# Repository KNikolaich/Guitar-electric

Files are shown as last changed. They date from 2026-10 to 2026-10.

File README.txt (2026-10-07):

ПРЕДУСИЛИТЕЛЬ ДЛЯ ГИТАРЫ: буфер + 2-полосный темброблок, 1S Li-ion,
громкость B500K push-pull (актив/пассив), светодиод питания
=============================================================================

СОСТАВ
  kicad/            проект KiCad 7+ (схема A3, плата, файл проекта)
  schematic.pdf     принципиальная схема (детали «вне платы» — в пунктирной рамке)
  etching/          для ЛУТ / фоторезиста, масштаб 1:1
     1_ETCH_bottom_copper_print_100pct.pdf   <- ПЕЧАТАТЬ ЭТО
     2_bottom_copper_as_seen_from_copper_side.pdf  (для сверки)
     3_assembly_top_100pct.pdf               расстановка деталей
  gerbers/          Gerber + сверловка (1 слой) для заказа на фабрике
  perfboard/        макетки: 30x70 мм (24x10 отв., компактная) и 61x41 мм (24x16 отв.)
  wiring_guitar.png проводка в корпусе: звукосниматели, RV1 push-pull, джек, TP4056, LED
  BOM.csv           перечень деталей (выводная плата)
  --- SMD-вариант конечной платы 60x29 мм ---
  kicad_smd/        проект KiCad: схема (та же, футпринты SMD) + плата
  etching_smd/      1_ETCH_bottom_copper_print_100pct.pdf  <- ПЕЧАТАТЬ ЭТО
  assembly_smd/     сборочный чертёж со стороны меди + подписи площадок сверху
  gerbers_smd/      Gerber + сверловка
  BOM_SMD.csv       перечень деталей SMD

ИЗМЕНЕНИЯ ОТНОСИТЕЛЬНО ПЕРВОЙ ВЕРСИИ
  - Громкость RV1 (B500K, Musiclily M908) стоит ДО платы, сразу после переключателя
    звукоснимателей, и работает в обоих режимах. На лепестках 3–2 стоит treble bleed (150k ‖ 1n).
  - Push-pull (DPDT) RV1:
      секция A: A2 (общий) → Tip;  A3 ← OUT платы (актив);  A1 — свободен (пассив)
      секция B: B5 (общий) ← движок RV1;  B6 → IN платы (актив);  B4 → Tip (пассив)
    Какое положение ручки какое — проверить тестером; при необходимости поменять
    местами провода на крайних лепестках ОБЕИХ секций (A1<->A3 и B4<->B6).
    В пассиве и вход, и выход платы отключены от сигнала — байпас работает
    даже с полностью севшим аккумулятором.
  - Один выходной джек — СТЕРЕО-гнездо TRS, кабель обычный моно. Ring ← OUT− модуля TP4056:
    штекер замыкает Ring на Sleeve и включает питание, кабель вынут — выключено.
  - На плате больше нет площадок VOL. Выход: C9 -> R9 -> OUT, R13 100k на землю
    (без щелчков при переключении).
  - C1 = 47 пФ (меньше «съедает» верх вместе с потенциометром 500k).
  - Светодиод D1 (через R15 4.7k, ~0.4 мА) — индикатор питания. Горит, когда
    вставлен кабель и аккумулятор жив. Двухсекционный push-pull полностью занят
    сигналом, поэтому плата получает питание и в пассиве с вставленным кабелем:
    светодиод горит, плата потребляет ~1–2.5 мА, но в звуке не участвует.
    Чтобы светодиод и питание отключались и в пассиве, нужен 4PDT push-pull
    или отдельный тумблер.
  - U1: MCP6022 (DIP-8) или OPA2316IDR на переходнике SOIC->DIP. Схема одинаковая.
    Ставьте цанговую панельку: чипы можно менять без пайки (только без кабеля в джеке).

ПЛАТА
  70 x 50 мм, односторонняя, все детали выводные. Дорожки 0.8 мм, зазоры не
  меньше 0.4 мм, остальная медь залита землёй. Перемычек нет.
  Отверстия 0.8 мм под детали, 1.1 мм под провода.
  Площадки для проводов: IN/GND (J1), BAT+ (J2), OUT/GND (J3), LED+/LED− (J7),
  B1..B3 (BASS), T1..T3 (TREBLE), x2 (JP1).
  Печать для ЛУТ: 100% / «Фактический размер», НЕ зеркалить. Надпись «GTR PRE v3»
  на распечатке читается зеркально. Ширина контура 70.0 мм — проверьте линейкой.

ПЛАТА SMD 60 x 29 мм (kicad_smd/)
  Односторонняя, детали SMD паяются СО СТОРОНЫ МЕДИ. Перемычек нет.
  Резисторы и конденсаторы 1206, ОУ SOIC-8 (MCP6022-I/SN или OPA2316IDR,
  без панельки и переходника), C3/C9 — SMD-электролиты 4x5.4 мм.
  Дорожки 0.6 мм, зазоры 0.35 мм, заливка земли с зазором 0.5 мм.
  Все провода — по бокам, отверстия 1.0 мм (площадки 2.1 мм):
    левый край  (сверху вниз): LED−/GND, LED+, BAT+, IN, GND
    правый край (сверху вниз): GND, OUT, TRE1, BAS1, BAS2, TRE2, BAS3, TRE3
  Площадки BASS и TREBLE чередуются — так плату удалось развести без перемычек.
  Номер = номер лепестка потенциометра, как на wiring_guitar.png.
  Отличия по деталям: C10 и C12 — керамика 22 мкФ X5R 1206 вместо электролитов 100 мкФ.
  JP1 — резистор 0 Ом 1206 (или капля припоя), есть = x2.
  Все сигнальные конденсаторы (C1, C2, C4–C8) — только C0G/NP0, не X7R.
  Печать для ЛУТ: 100%, не зеркалить; «GTR PRE SMD» на распечатке читается зеркально.
  Ширина контура 60.0 мм. Сборка: сначала U1, потом 1206, электролиты и провода последними.
  Проверено: DRC без ошибок, все 34 детали соединены по схеме.

МАКЕТКА 30x70 мм (24x10 отв.) — для тесной полости
  Файлы: perfboard/perfboard_30x70_*.  Столбцы A..X по длинной стороне,
  строки 1..10 по короткой (сверху вниз, вид со стороны деталей).
  - Все резисторы стоят вертикально (корпус над выводом 1).
  - Плёночные C2, C4–C7 — шаг 5 мм; керамика C1, C8, C11 — шаг 2.5 мм;
    электролиты: 10 мкФ Ø5 мм, 100 мкФ Ø6.3 мм (шаг 2.5 мм).
  - Одна перемычка W1 (L6–L8, земля) изолированным проводом сверху, над R1.
  - Высота сборки ~12 мм (самые высокие — электролиты и стоящие резисторы).
  Связность проверена скриптом против схемы.

МАКЕТКА 61x41 мм (24x16 отв.)
  Файлы: perfboard/perfboard_component_side.png и т.д. Три перемычки W1–W3,
  координаты — в perfboard_coordinates.txt.

ПРОВЕРКА ПОСЛЕ ПАЙКИ
  1. Без ОУ вставьте моно-штекер в джек: на выводе 8 панельки 3.0–4.2 В, светодиод горит.
  2. С ОУ: на выводах 5, 1, 7 около половины питания (~1.85 В).
     Ток: MCP6022 ~2.5 мА, OPA2316 ~1.2 мА (вместе со светодиодом).
  3. Ручка нажата — звук идёт через темброблок (BASS/TREBLE работают).
     Ручка вытянута — темброблок не действует (пассив).

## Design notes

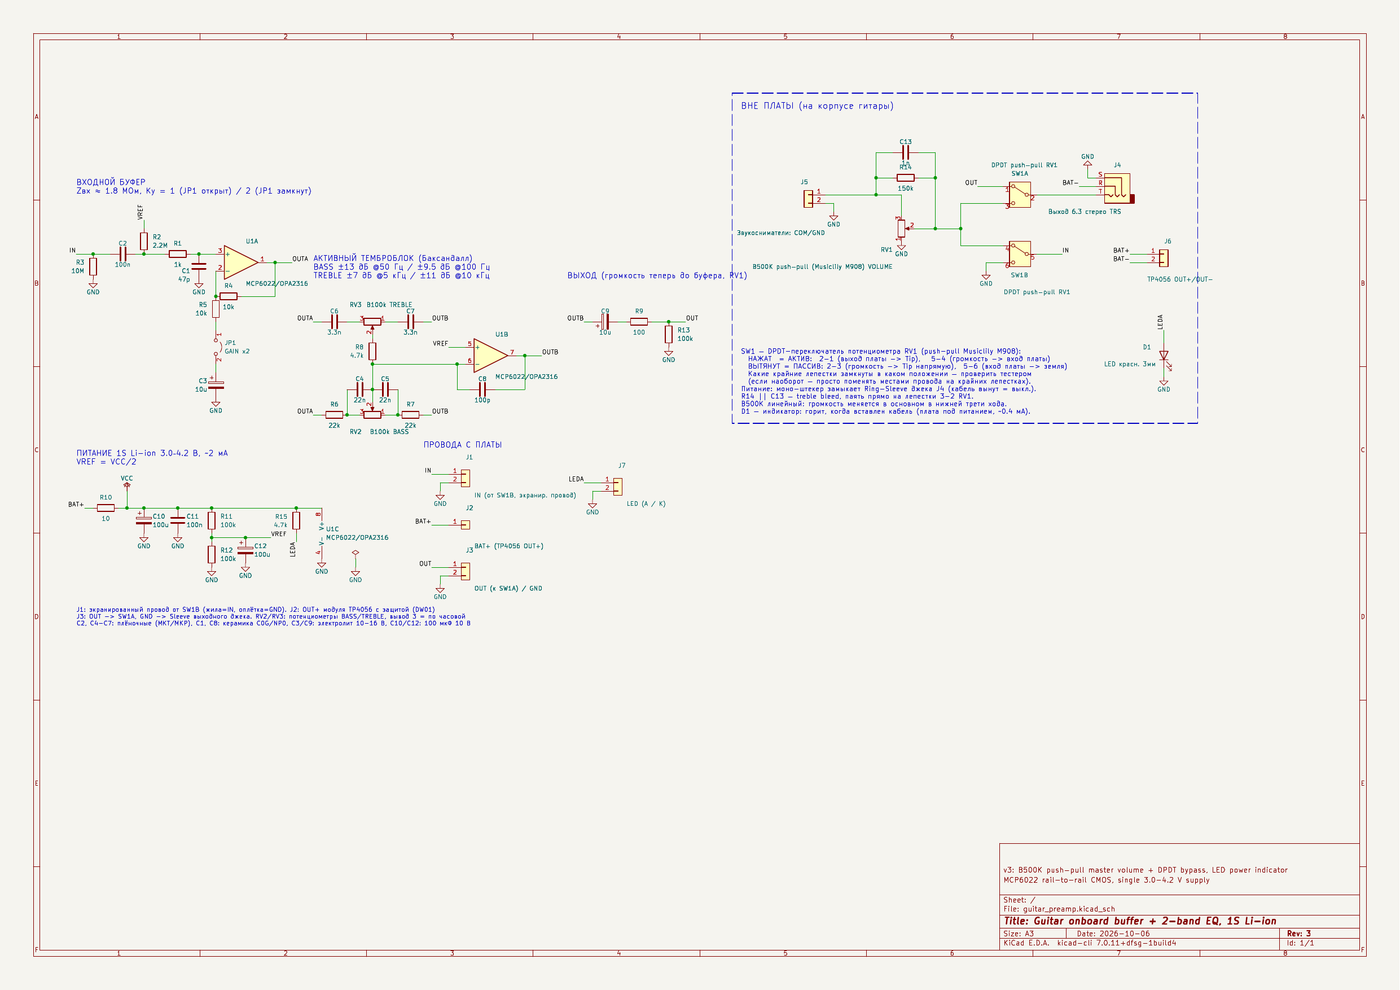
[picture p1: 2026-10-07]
schematic.png

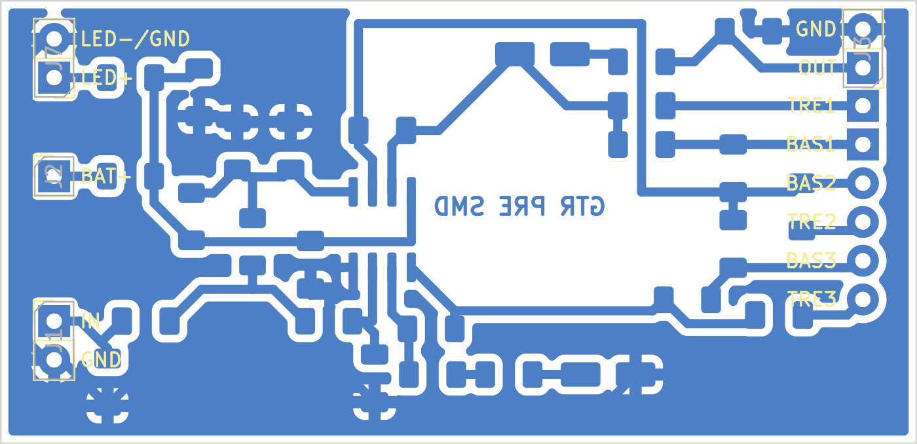
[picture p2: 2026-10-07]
pcb_smd_preview.png

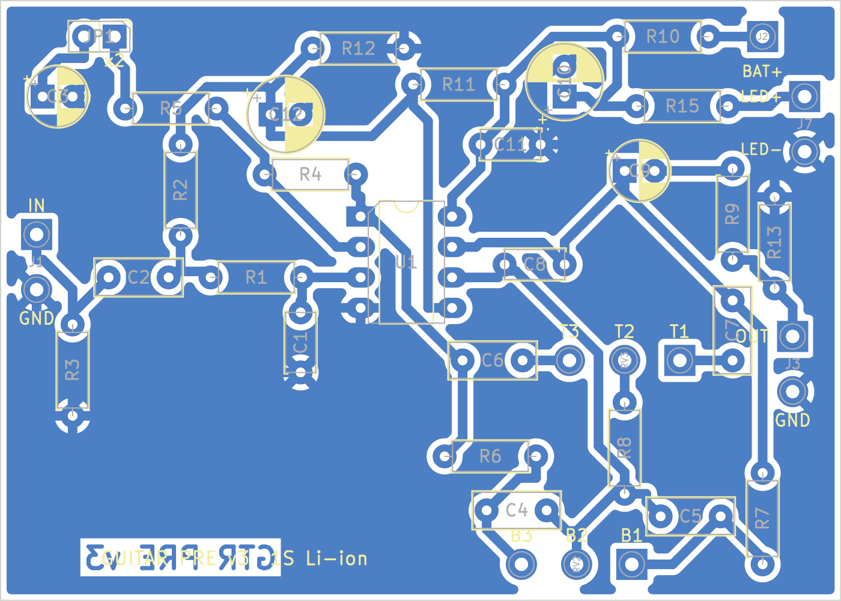
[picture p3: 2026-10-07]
pcb_preview_top.png

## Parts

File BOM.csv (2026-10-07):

Позиции | Кол-во | Номинал | Тип | Где | Примечание | Футпринт KiCad
C1 | 1 | 47p | Конденсатор | плата | керамика C0G/NP0 | C_Disc_D5.0mm_W2.5mm_P5.00mm
C2 | 1 | 100n | Конденсатор | плата | C2 — плёнка MKT/MKP 63 В шаг 5 мм; C11 — керамика | C_Rect_L7.2mm_W3.0mm_P5.00mm_FKS2_FKP2_MKS2_MKP2
C3, C9 | 2 | 10u | Конденсатор | плата | электролит 16 В, Ø5 мм, шаг 2.5 | CP_Radial_D5.0mm_P2.50mm
C4, C5 | 2 | 22n | Конденсатор | плата | плёнка MKT, шаг 5 мм | C_Rect_L7.2mm_W3.0mm_P5.00mm_FKS2_FKP2_MKS2_MKP2
C6, C7 | 2 | 3.3n | Конденсатор | плата | плёнка MKT, шаг 5 мм | C_Rect_L7.2mm_W3.0mm_P5.00mm_FKS2_FKP2_MKS2_MKP2
C8 | 1 | 100p | Конденсатор | плата | керамика C0G/NP0 | C_Disc_D5.0mm_W2.5mm_P5.00mm
C10, C12 | 2 | 100u | Конденсатор | плата | электролит 10 В, Ø6.3 мм, шаг 2.5 | CP_Radial_D6.3mm_P2.50mm
C11 | 1 | 100n | Конденсатор | плата | C2 — плёнка MKT/MKP 63 В шаг 5 мм; C11 — керамика | C_Disc_D5.0mm_W2.5mm_P5.00mm
JP1 | 1 | GAIN x2 | Перемычка | плата | 2 штыря + джампер или капля припоя | PinHeader_1x02_P2.54mm_Vertical
R1 | 1 | 1k | Резистор 0.25 Вт металлоплёночный | плата |  | R_Axial_DIN0207_L6.3mm_D2.5mm_P7.62mm_Horizontal
R2 | 1 | 2.2M | Резистор 0.25 Вт металлоплёночный | плата |  | R_Axial_DIN0207_L6.3mm_D2.5mm_P7.62mm_Horizontal
R3 | 1 | 10M | Резистор 0.25 Вт металлоплёночный | плата |  | R_Axial_DIN0207_L6.3mm_D2.5mm_P7.62mm_Horizontal
R4, R5 | 2 | 10k | Резистор 0.25 Вт металлоплёночный | плата |  | R_Axial_DIN0207_L6.3mm_D2.5mm_P7.62mm_Horizontal
R6, R7 | 2 | 22k | Резистор 0.25 Вт металлоплёночный | плата |  | R_Axial_DIN0207_L6.3mm_D2.5mm_P7.62mm_Horizontal
R8, R15 | 2 | 4.7k | Резистор 0.25 Вт металлоплёночный | плата | R8 — тембр; R15 — ток светодиода ~0.4 мА | R_Axial_DIN0207_L6.3mm_D2.5mm_P7.62mm_Horizontal
R9 | 1 | 100 | Резистор 0.25 Вт металлоплёночный | плата |  | R_Axial_DIN0207_L6.3mm_D2.5mm_P7.62mm_Horizontal
R10 | 1 | 10 | Резистор 0.25 Вт металлоплёночный | плата |  | R_Axial_DIN0207_L6.3mm_D2.5mm_P7.62mm_Horizontal
R11, R12, R13 | 3 | 100k | Резистор 0.25 Вт металлоплёночный | плата |  | R_Axial_DIN0207_L6.3mm_D2.5mm_P7.62mm_Horizontal
RV2 | 1 | B100k BASS | Потенциометр | вне платы (провода к площадкам BAS/TRE) | линейный 16 мм, на корпусе | SolderWire-0.5sqmm_1x03_P4.6mm_D0.9mm_OD2.1mm
RV3 | 1 | B100k TREBLE | Потенциометр | вне платы (провода к площадкам BAS/TRE) | линейный 16 мм, на корпусе | SolderWire-0.5sqmm_1x03_P4.6mm_D0.9mm_OD2.1mm
U1 | 1 | MCP6022/OPA2316 | ОУ | плата | DIP-8 в цанговую панельку. OPA2316IDR (SOIC-8) — через переходник SOIC→DIP | DIP-8_W7.62mm_LongPads
C13 | 1 | 1n | Конденсатор | вне платы | treble bleed, плёнка/керамика C0G, на лепестках 3–2 RV1
D1 | 1 | LED красн. 3мм | Светодиод | вне платы
R14 | 1 | 150k | Резистор 0.25 Вт металлоплёночный | вне платы | treble bleed, на лепестках 3–2 RV1
RV1 | 1 | B500K push-pull (Musiclily M908) VOLUME | Потенциометр | вне платы | Musiclily M908, DPDT push-pull (SW1 в нём же)
— | 1 | Панелька DIP-8 цанговая |  | плата | под U1
— | 1 | Аккумулятор 1S Li-ion/LiPo 3.7 В 300–1000 мА·ч |  | вне платы
— | 1 | Модуль TP4056 с защитой (DW01), USB-C |  | вне платы | OUT+ → BAT+ платы, OUT− → Ring джека
— | 1 | Гнездо 6.3 мм СТЕРЕО (TRS) |  | вне платы | Tip ← SW1 A2, Ring ← OUT− TP4056, Sleeve ← GND платы
— | 1 | Экранированный провод 1 жила |  | вне платы | SW1 B5 → IN платы

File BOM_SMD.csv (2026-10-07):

Позиции | Кол-во | Номинал | Тип | Корпус / футпринт | Примечание
U1 | 1 | MCP6022-I/SN или OPA2316IDR | ОУ | SOIC-8 | паяется прямо на плату (без панельки)
C1 | 1 | 47p | Конденсатор | 1206 | керамика C0G/NP0
C2 | 1 | 100n | Конденсатор | 1206 | керамика C0G/NP0 50 В (НЕ X7R — микрофонный эффект и искажения)
C4, C5 | 2 | 22n | Конденсатор | 1206 | керамика C0G/NP0
C6, C7 | 2 | 3.3n | Конденсатор | 1206 | керамика C0G/NP0
C8 | 1 | 100p | Конденсатор | 1206 | керамика C0G/NP0
C11 | 1 | 100n | Конденсатор | 1206 | керамика X7R
C10, C12 | 2 | 22u | Конденсатор | 1206 | керамика X5R/X7R ≥10 В (вместо электролитов 100u)
C3, C9 | 2 | 10u | Конденсатор | SMD-электролит 4x5.4 мм | 16 В; «+» по сборочному чертежу
R1 | 1 | 1k | Резистор | 1206
R2 | 1 | 2.2M | Резистор | 1206
R3 | 1 | 10M | Резистор | 1206
R4, R5 | 2 | 10k | Резистор | 1206
R6, R7 | 2 | 22k | Резистор | 1206
R8, R15 | 2 | 4.7k | Резистор | 1206 | R15 — ток светодиода ~0.4 мА
R9 | 1 | 100 | Резистор | 1206
R10 | 1 | 10 | Резистор | 1206
R11, R12, R13 | 3 | 100k | Резистор | 1206
JP1 | 1 | 0R | Перемычка | 1206 | есть = усиление x2 (+6 дБ), нет = x1; можно каплю припоя
J1, J2, J3, J7, RV2, RV3 | — | площадки | Провода | отв. 1.0 мм, площадка 2.1 мм | провода вставляются со стороны без меди
RV2 | 1 | B100k BASS | Потенциометр | вне платы | линейный, на корпусе
RV3 | 1 | B100k TREBLE | Потенциометр | вне платы | линейный, на корпусе
RV1 + SW1 | 1 | B500K push-pull (Musiclily M908) | Потенциометр | вне платы | громкость + DPDT актив/пассив
R14 | 1 | 150k | Резистор | вне платы | treble bleed, на лепестках 3–2 RV1
C13 | 1 | 1n | Конденсатор | вне платы | treble bleed, плёнка/C0G, на лепестках 3–2 RV1
D1 | 1 | LED красн. 3 мм | Светодиод | вне платы
— | 1 | Модуль TP4056 с защитой (DW01), USB-C |  | вне платы | OUT+ → BAT+ платы, OUT− → Ring джека
— | 1 | Аккумулятор 1S Li-ion/LiPo 3.7 В 300–1000 мА·ч |  | вне платы
— | 1 | Гнездо 6.3 мм СТЕРЕО (TRS) |  | вне платы | Tip ← SW1 A2, Ring ← OUT− TP4056, Sleeve ← GND
— | 1 | Экранированный провод 1 жила |  | вне платы | SW1 B6 → IN платы

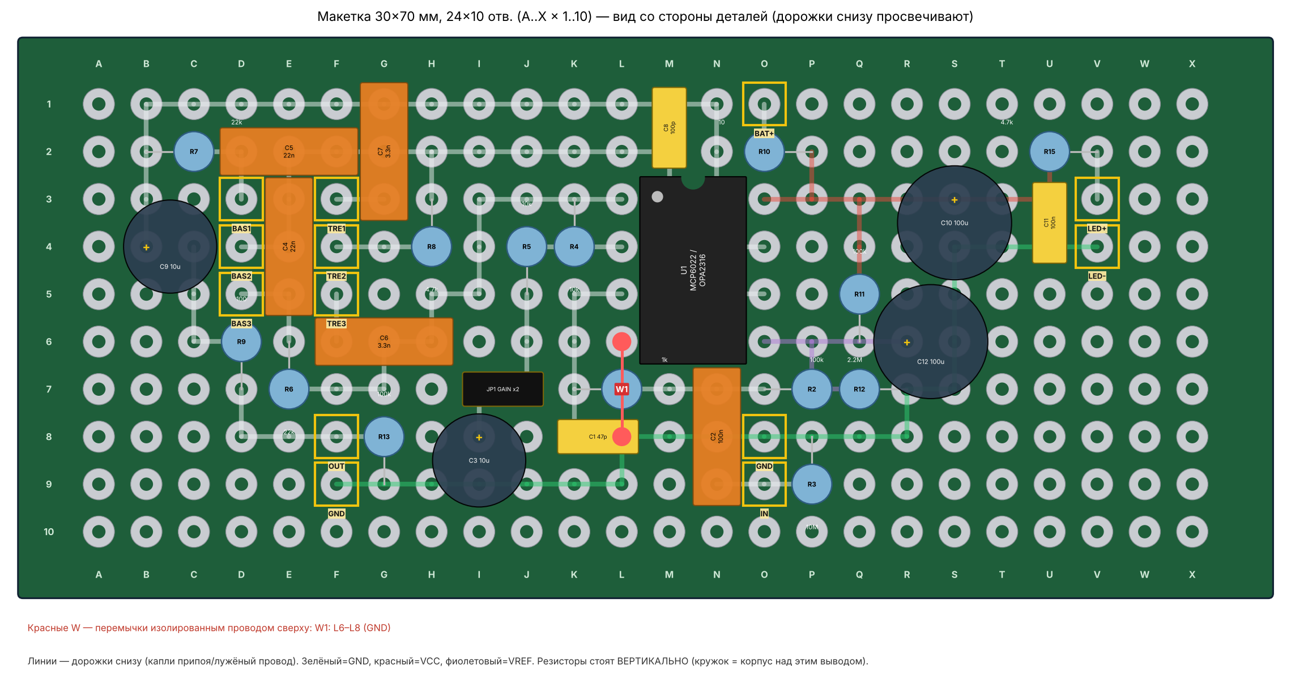
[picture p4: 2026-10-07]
perfboard/perfboard_30x70_component_side.png

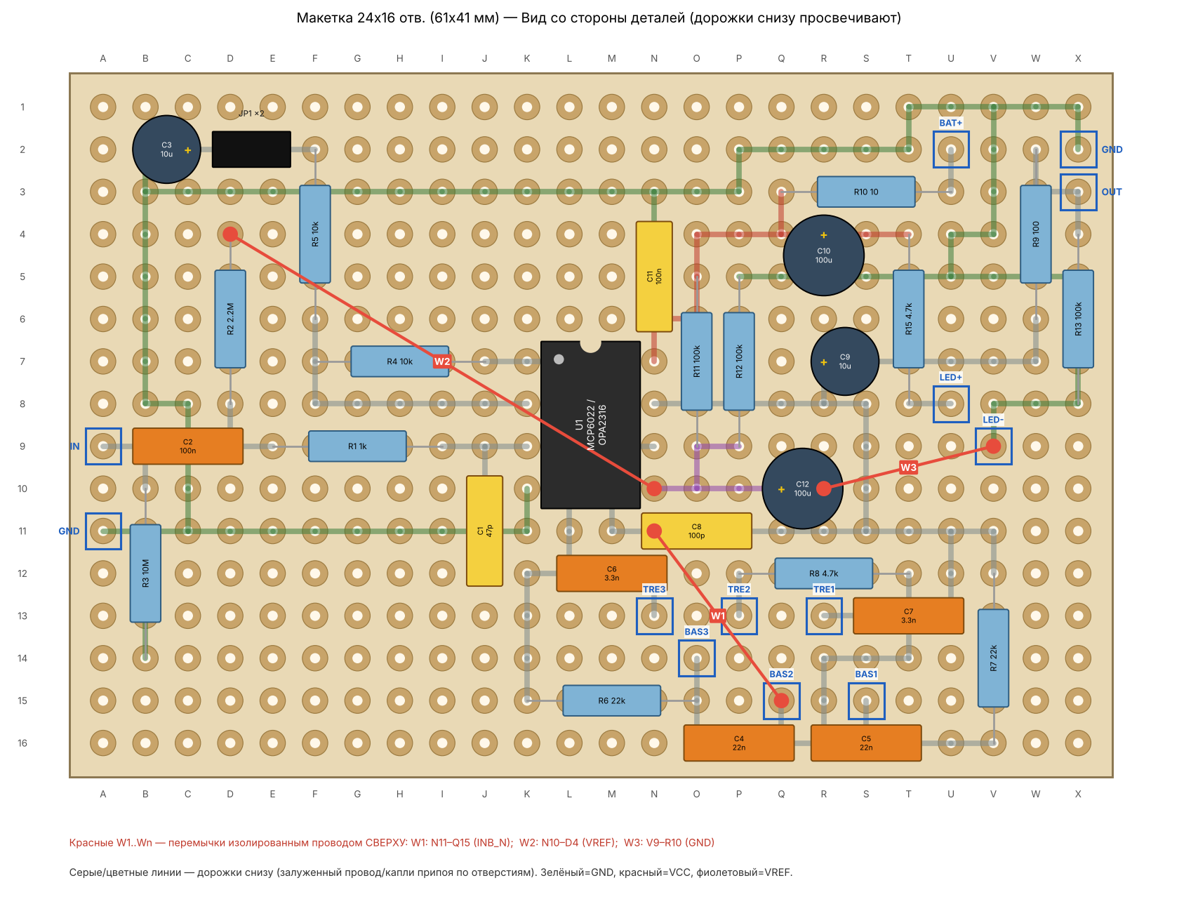
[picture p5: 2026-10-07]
perfboard/perfboard_component_side.png

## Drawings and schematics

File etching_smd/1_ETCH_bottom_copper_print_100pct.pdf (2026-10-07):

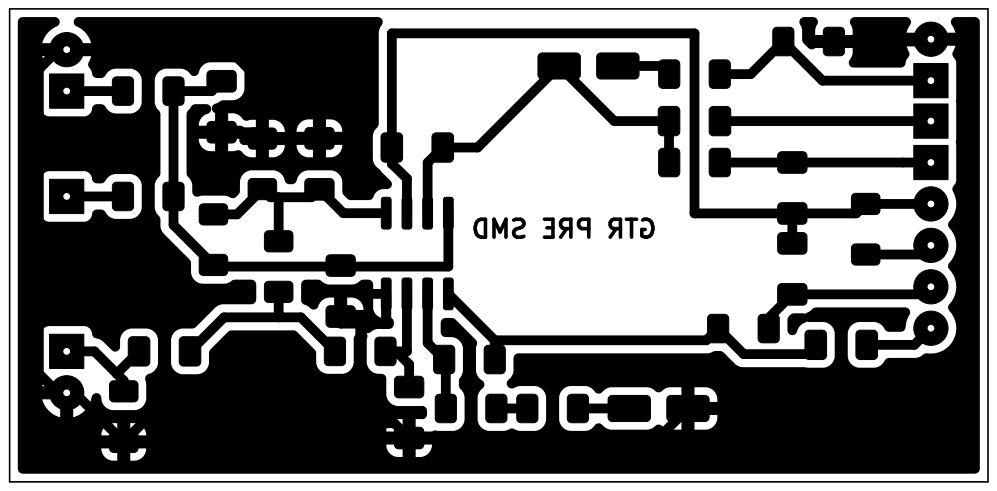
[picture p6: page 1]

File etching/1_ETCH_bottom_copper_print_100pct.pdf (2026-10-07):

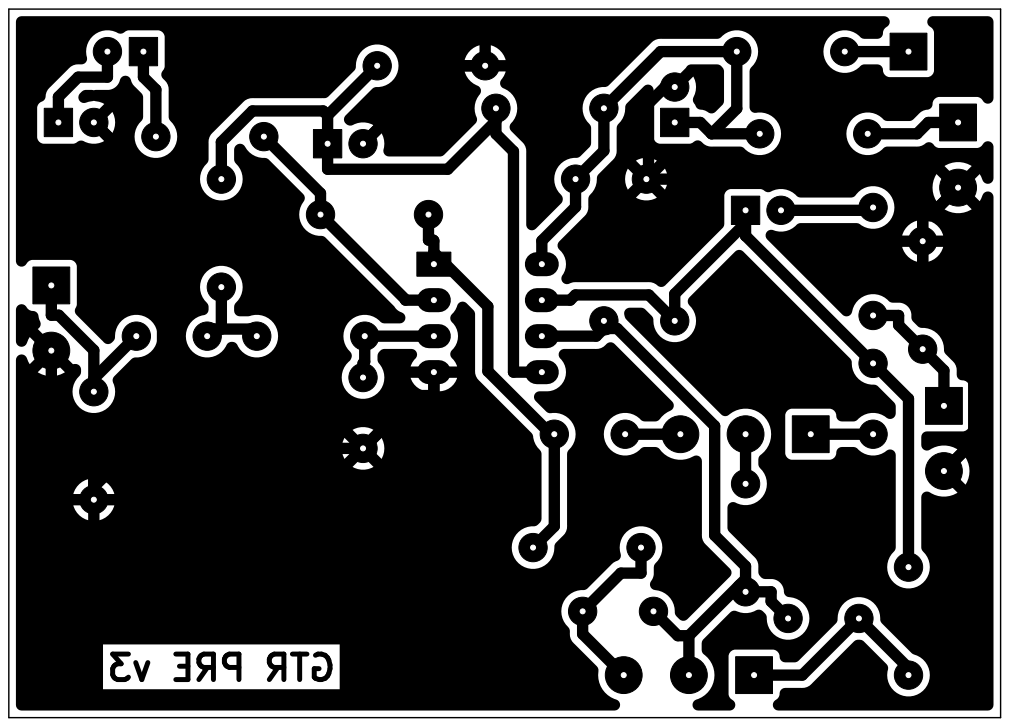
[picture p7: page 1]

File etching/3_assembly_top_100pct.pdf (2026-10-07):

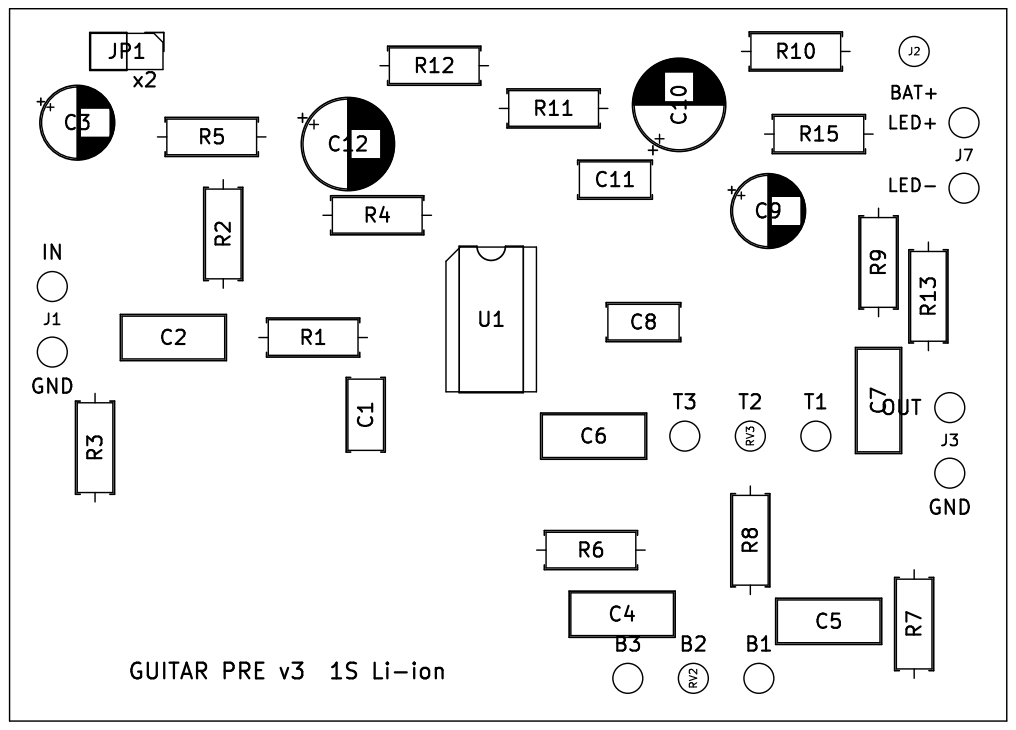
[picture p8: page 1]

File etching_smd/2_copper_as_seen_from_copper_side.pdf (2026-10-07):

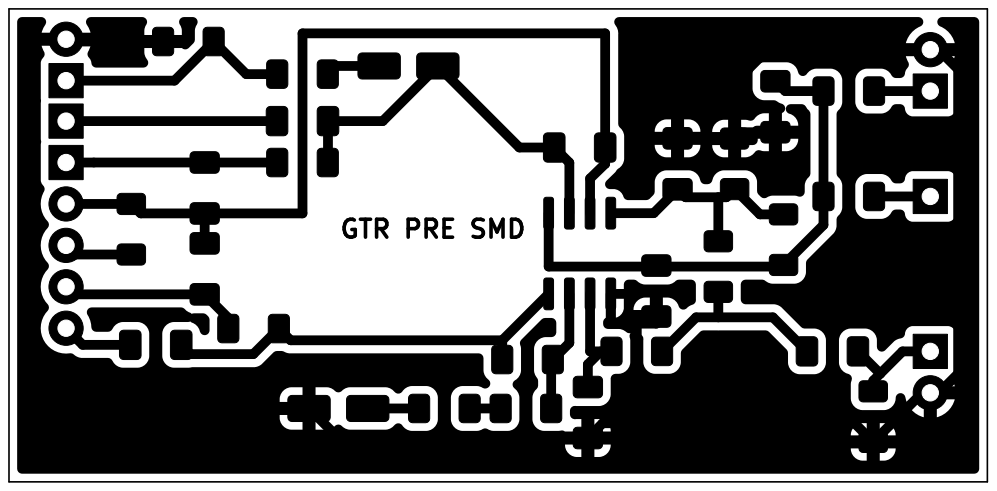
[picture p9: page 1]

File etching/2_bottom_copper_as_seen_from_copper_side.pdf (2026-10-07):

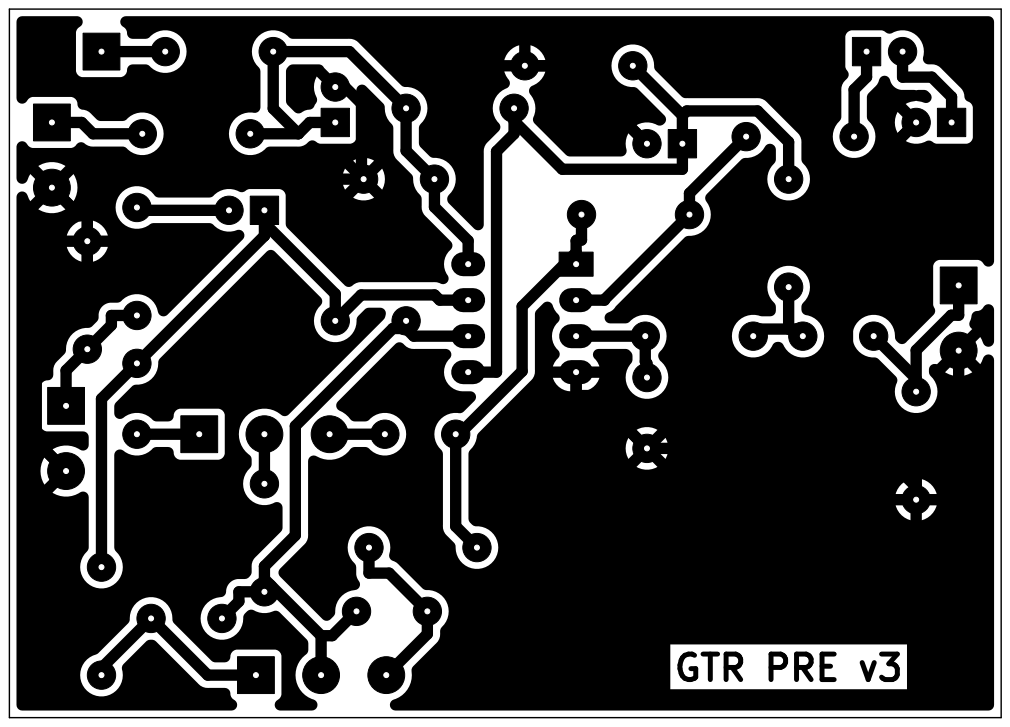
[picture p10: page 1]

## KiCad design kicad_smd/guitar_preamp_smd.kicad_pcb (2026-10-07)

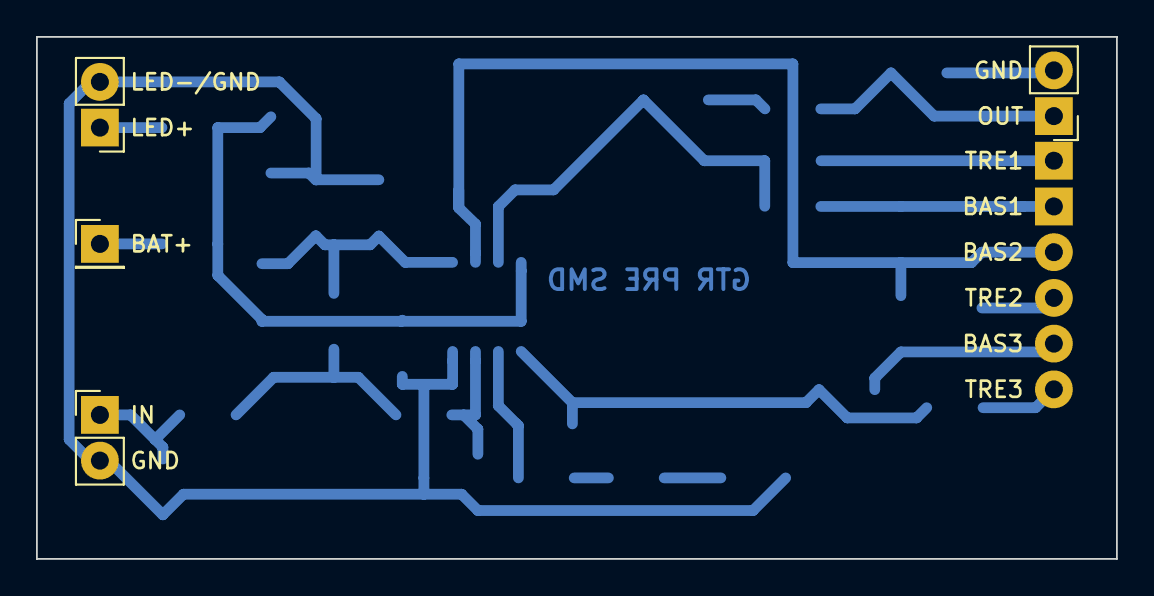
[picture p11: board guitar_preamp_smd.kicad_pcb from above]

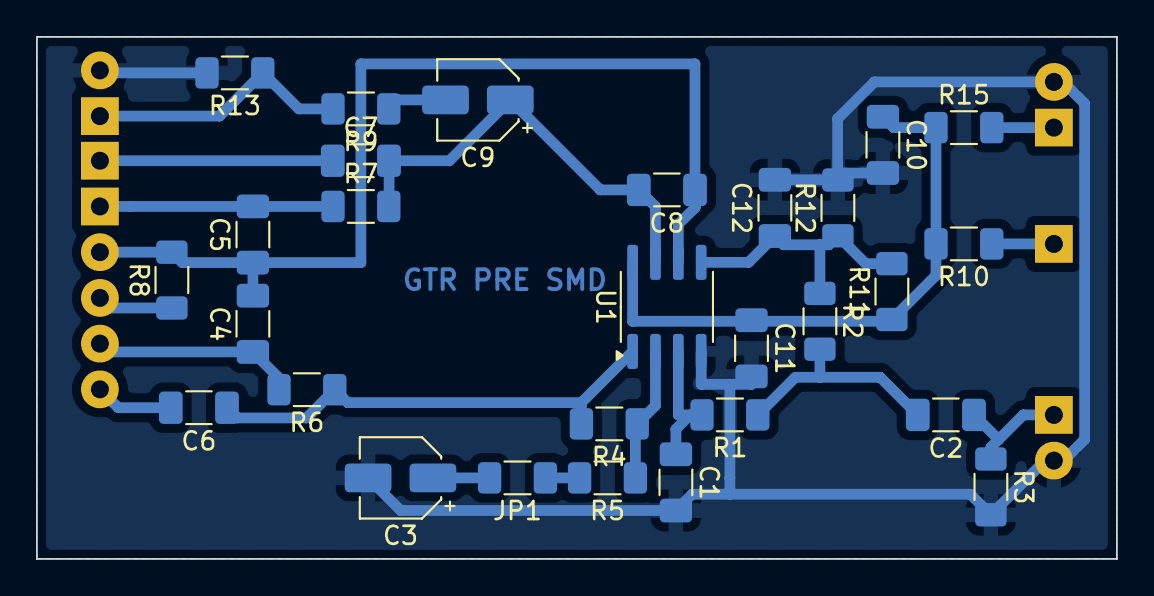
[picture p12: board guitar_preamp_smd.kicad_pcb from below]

Board: 2 copper layers, 60.0 x 29.0 mm, 34 parts (28 on the bottom side), 21 nets.

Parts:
C1: 47p; C_1206_3216Metric_Pad1.33x1.80mm_HandSolder
C2, C11: 100n; C_1206_3216Metric_Pad1.33x1.80mm_HandSolder
C3, C9: 10u; CP_Elec_4x5.4
C4, C5: 22n; C_1206_3216Metric_Pad1.33x1.80mm_HandSolder
C6, C7: 3.3n; C_1206_3216Metric_Pad1.33x1.80mm_HandSolder
C8: 100p; C_1206_3216Metric_Pad1.33x1.80mm_HandSolder
C10, C12: 22u; C_1206_3216Metric_Pad1.33x1.80mm_HandSolder
J1: IN (от SW1B, экранир. провод); PinHeader_1x02_P2.54mm_Vertical
J2: BAT+ (TP4056 OUT+); PinHeader_1x01_P2.54mm_Vertical
J3: OUT (к SW1A) / GND; PinHeader_1x02_P2.54mm_Vertical
J7: LED (A / K); PinHeader_1x02_P2.54mm_Vertical
JP1: GAIN x2 (0R = x2); R_1206_3216Metric_Pad1.30x1.75mm_HandSolder
R1: 1k; R_1206_3216Metric_Pad1.30x1.75mm_HandSolder
R2: 2.2M; R_1206_3216Metric_Pad1.30x1.75mm_HandSolder
R3: 10M; R_1206_3216Metric_Pad1.30x1.75mm_HandSolder
R4, R5: 10k; R_1206_3216Metric_Pad1.30x1.75mm_HandSolder
R6, R7: 22k; R_1206_3216Metric_Pad1.30x1.75mm_HandSolder
R8, R15: 4.7k; R_1206_3216Metric_Pad1.30x1.75mm_HandSolder
R9: 100; R_1206_3216Metric_Pad1.30x1.75mm_HandSolder
R10: 10; R_1206_3216Metric_Pad1.30x1.75mm_HandSolder
R11, R12, R13: 100k; R_1206_3216Metric_Pad1.30x1.75mm_HandSolder
RV2: B100k BASS; PinHeader_1x03_P2.54mm_Vertical
RV3: B100k TREBLE; PinHeader_1x03_P2.54mm_Vertical
U1: MCP6022/OPA2316; SOIC-8_3.9x4.9mm_P1.27mm

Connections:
B1: C4.1, R6.2, RV2.3
B2: C5.2, R7.1, RV2.1
BAT+: J2.1, R10.1
GND: C1.2, C3.2, C10.2, C11.2, C12.2, J1.2, J3.2, J7.2, R3.2, R12.2, R13.2, U1.4
IN: C2.1, J1.1, R3.1
INA_N: R4.1, R5.1, U1.2
INB_N: C4.2, C5.1, C8.1, R8.2, RV2.2, U1.6
INP: C1.1, R1.2, U1.3
LEDA: J7.1, R15.2
N1: C2.2, R1.1, R2.2
N2: JP1.1, R5.2
N3: C3.1, JP1.2
N4: C9.2, R9.1
OUT: J3.1, R9.2, R13.1
OUTA: C6.1, R4.2, R6.1, U1.1
OUTB: C7.2, C8.2, C9.1, R7.2, U1.7
T1: C6.2, RV3.3
T2: C7.1, RV3.1
TW: R8.1, RV3.2
VCC: C10.1, C11.1, R10.2, R11.1, R15.1, U1.8
VREF: C12.1, R2.1, R11.2, R12.1, U1.5

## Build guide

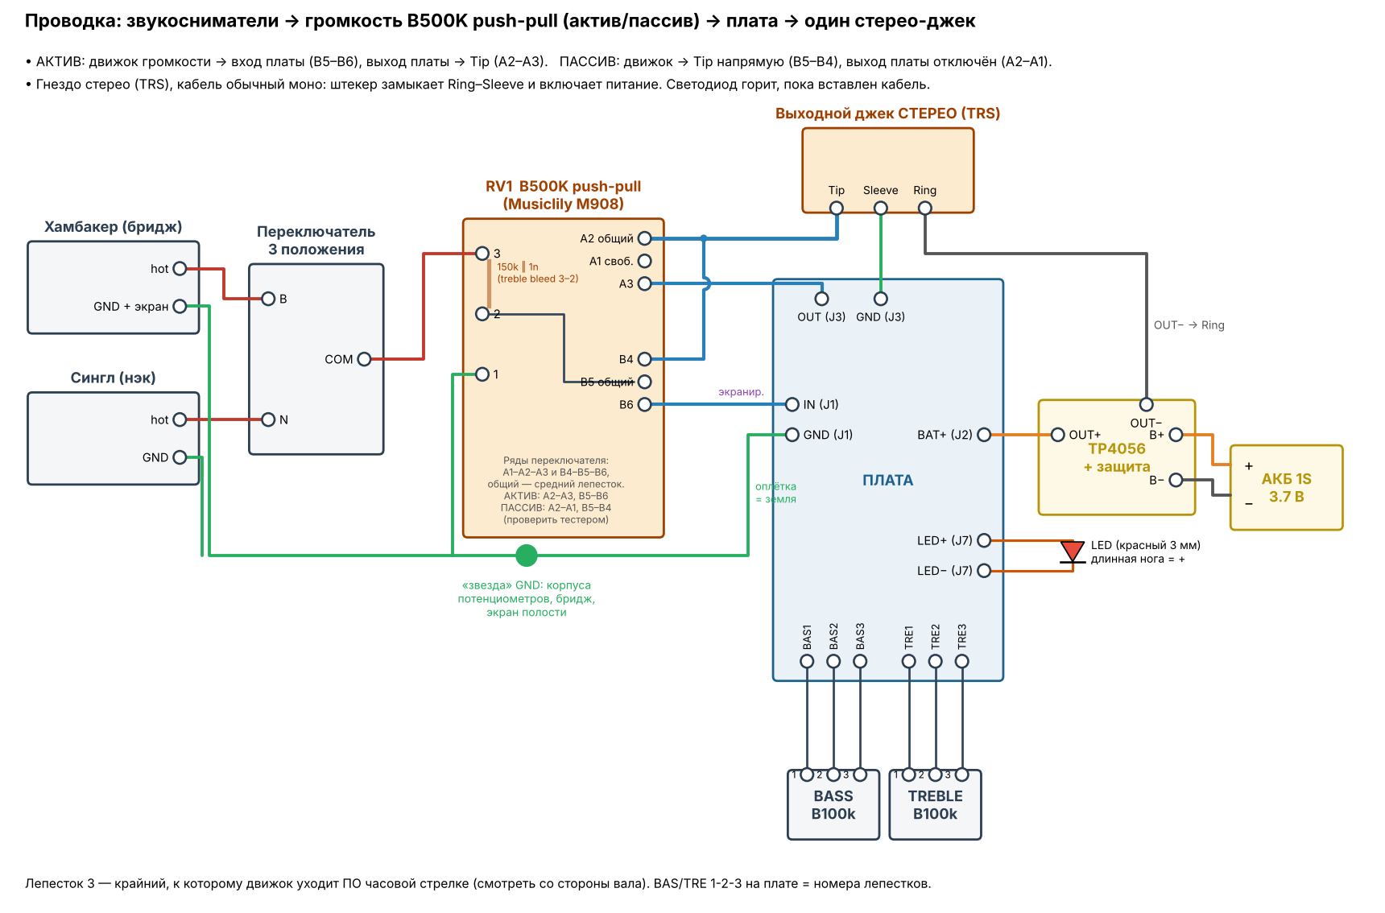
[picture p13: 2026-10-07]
wiring_guitar.png

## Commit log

2026-10-07 v1 Принципиальная схема Одна микросхема MCP6022, питание 1S (3,0–4,2 В). Средняя точка Vb ≈ 1,85 В: резисторы 100k (к V+) и 100k (к GND), к точке Vb конденсатор 47 мкФ на землю. Рядом с микросхемой п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
    [BOM.csv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]
2026-10-07 v3 ПРЕДУСИЛИТЕЛЬ ДЛЯ ГИТАРЫ v3: буфер + 2-полосный темброблок, 1S Li-ion, громкость B500K push-pull (актив/пассив), светодиод питания
    [BOM.csv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]
2026-10-07 Версия для малой платы прототипизирования 30х70.
2026-10-07 понятнее для меня подключение jeck
    [guitar_preamp.kicad_sch]
2026-10-07 мой вариант
    [guitar_preamp.kicad_sch]
2026-10-07 кутерьма с коннекторами
    [guitar_preamp.kicad_sch]
2026-10-07 переделка входного каскада
    [guitar_preamp.kicad_sch]
2026-10-07 раскладка для smd элементов
    [BOM_SMD.csv, guitar_preamp_smd.kicad_pcb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]
2026-10-25 подкрасил соединения
